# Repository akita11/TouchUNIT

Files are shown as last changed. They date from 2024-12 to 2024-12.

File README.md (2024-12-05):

# TouchUNIT

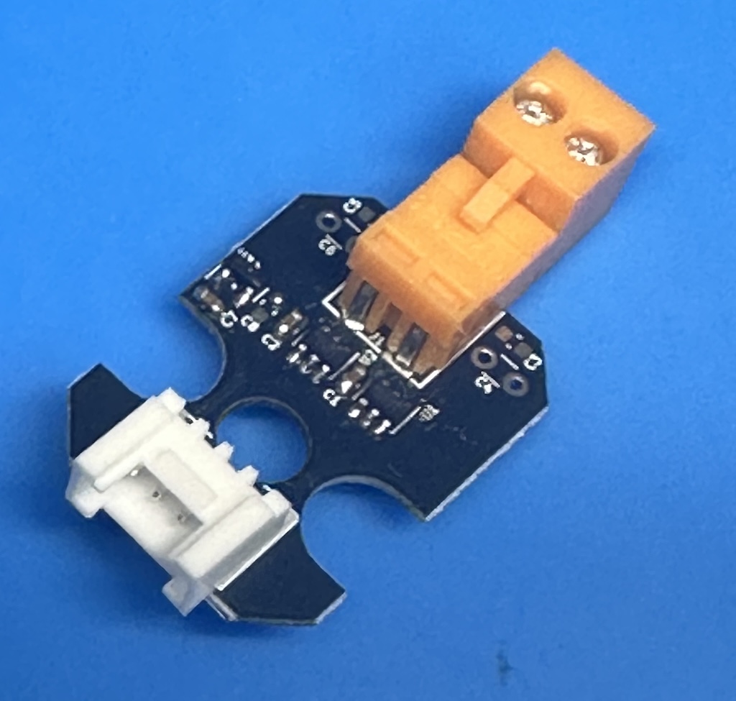
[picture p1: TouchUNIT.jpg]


タッチセンサICの[TTP223N-HA6](https://www.lcsc.com/product-detail/Touch-Sensors_Tontek-Design-Tech-TTP223N-HA6_C93723.html)を使用した、2系統のタッチセンサです。Grove端子の2本の信号線にタッチ状態を出力することができます。M5Stackの2個の物理スイッチがある[デュアルボタンUNIT](https://www.switch-science.com/products/4048)と同等の出力のため、UIFlow等ではこのデュアルボタンUNIT用のブロック・プログラムがそのまま使えます。

※[M5Stack用ADCユニット](https://www.switch-science.com/products/9491)と形状が互換なので、そのケースを流用できます。

## 使い方

オレンジのネジ端子にタッチ電極を接続します。T1とT2の独立の2系統のタッチ検出を使用できます。手を近づけただけでONとなるなどタッチ検出の感度が高すぎる場合は、後述の方法で感度を調整してください。（標準状態より感度を高めることは原理上できません）

## 設定の変更

### タッチ検出の感度の変更

基板上にコンデンサを取り付けることで、タッチ検出の感度を調整（低くする）ことができます。実際の使用状況にあわせて、適切な容量のコンデンサを接続してください。容量値や動作原理などはタッチ検出IC(TTP223N)のデータシートを参照してください。

- T1 : C3（1608サイズ表面実装）またはC4（挿入実装）
- T2 : C5（1608サイズ表面実装）またはC6（挿入実装）

### 出力信号の極性・トグルの設定

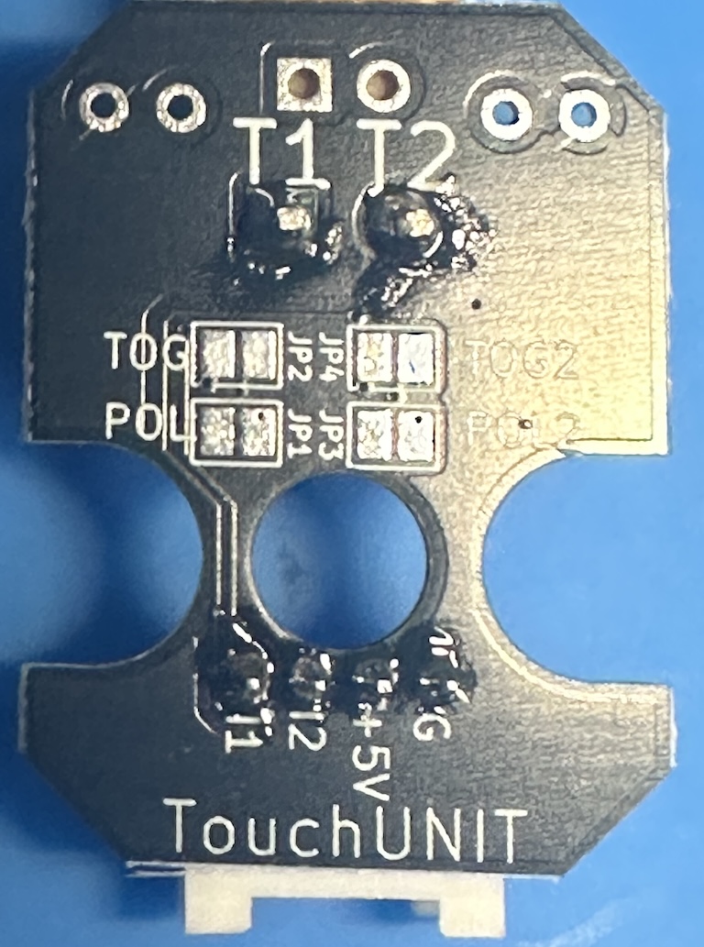
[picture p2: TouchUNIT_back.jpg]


基板裏面の半田ジャンパによって、出力の動作モードを設定できます。詳細はタッチ検出IC(TTP223N)のデータシートと回路図を参照してください。

- POL1(JP1/T1用)/POL2(JP3/T2用): ショート（標準設定）=タッチ時'0'／開放（パターンカット）=タッチ時'1'
- TOG1(JP2/T1用)/TOG2(JP4/T2用): 開放（標準設定）=タッチ時のみ0/1／ショート（半田を盛る）=タッチごとに出力がトグル

## Author

Junichi Akita (akita@ifdl.jp, @akita11)

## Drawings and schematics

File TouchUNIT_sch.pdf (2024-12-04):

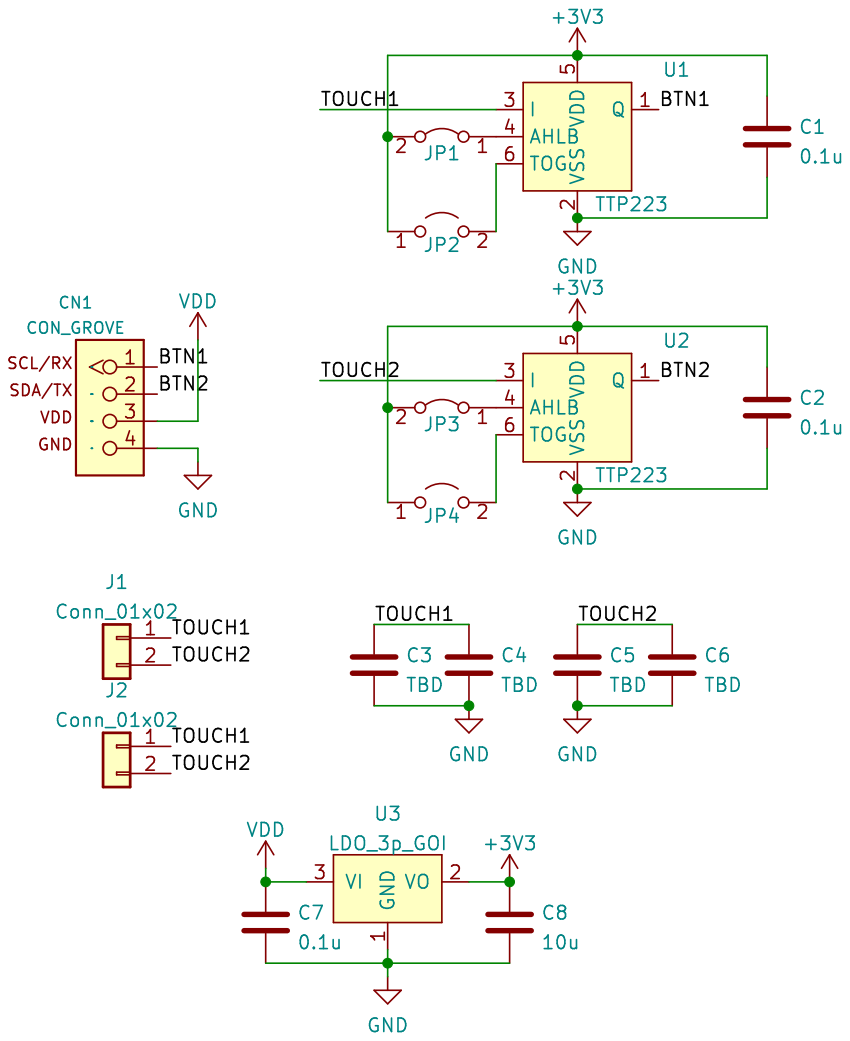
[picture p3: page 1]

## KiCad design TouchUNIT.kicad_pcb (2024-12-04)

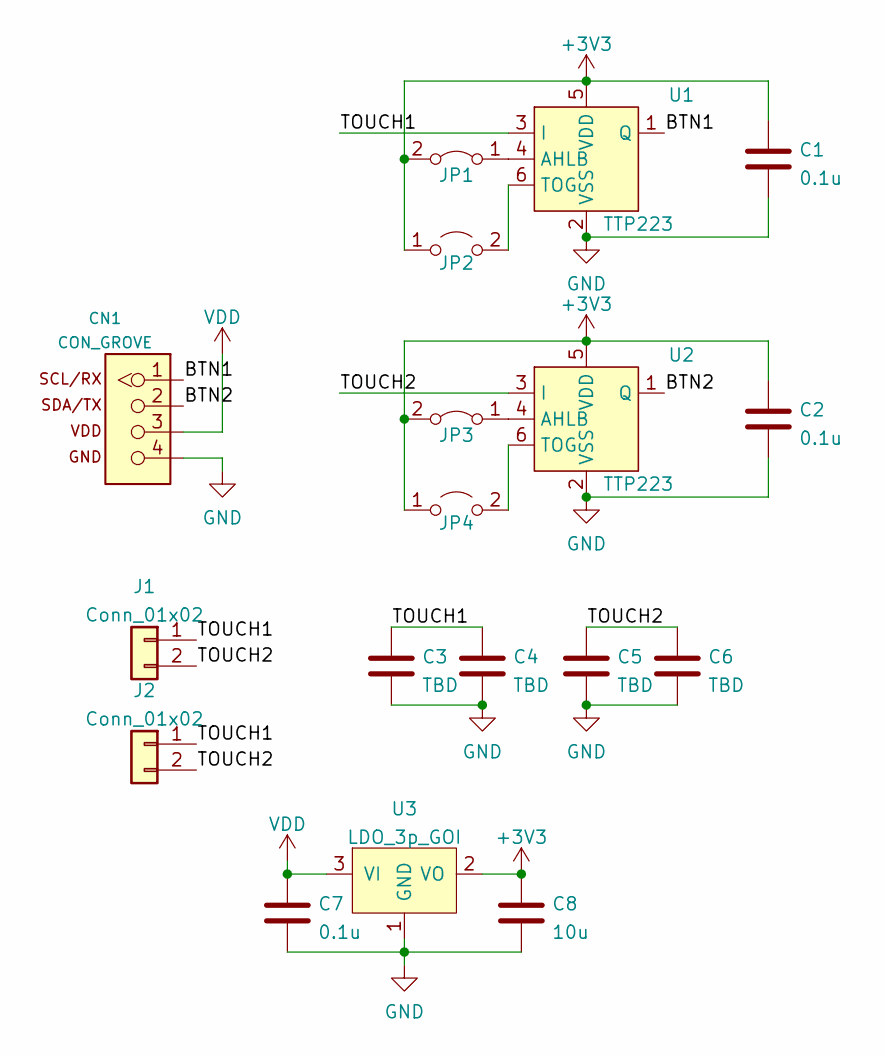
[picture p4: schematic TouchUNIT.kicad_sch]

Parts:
C1, C2, C7: 0.1u; C_0603_1608Metric
C3, C5: TBD; C_0603_1608Metric
C4, C6: TBD; C_Disc_D3.0mm_W1.6mm_P2.50mm
C8: 10u; C_0603_1608Metric
CN1: CON_GROVE; CON_GROVE_H
J1: Conn_01x02; CON_HT396R_2P
J2: Conn_01x02; PinSocket_1x02_P2.54mm_Vertical
JP1, JP3: Jumper_2_Bridged; SolderJumper-2_P1.3mm_Bridged2Bar_Pad1.0x1.5mm
JP2, JP4: Jumper_2_Open; SolderJumper-2_P1.3mm_Open_Pad1.0x1.5mm
U1, U2: TTP223; SOT-23-6
U3: LDO_3p_GOI; SOT-23

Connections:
+3V3: C1.1, C2.1, C8.1, JP1.2 (B), JP2.1 (A), JP3.2 (B), JP4.1 (A), U1.5 (VDD), U2.5 (VDD), U3.2 (VO)
/BTN1: CN1.1, U1.1 (Q)
/BTN2: CN1.2, U2.1 (Q)
/TOUCH1: C3.1, C4.1, J1.1, J2.1, U1.3 (I)
/TOUCH2: C5.1, C6.1, J1.2, J2.2, U2.3 (I)
GND: C1.2, C2.2, C3.2, C4.2, C5.2, C6.2, C7.2, C8.2, CN1.4, U1.2 (VSS), U2.2 (VSS), U3.1 (GND)
unnamed: JP1.1 (A), U1.4 (AHLB)
unnamed: JP2.2 (B), U1.6 (TOG)
unnamed: JP3.1 (A), U2.4 (AHLB)
unnamed: JP4.2 (B), U2.6 (TOG)
VDD: C7.1, CN1.3, U3.3 (VI)

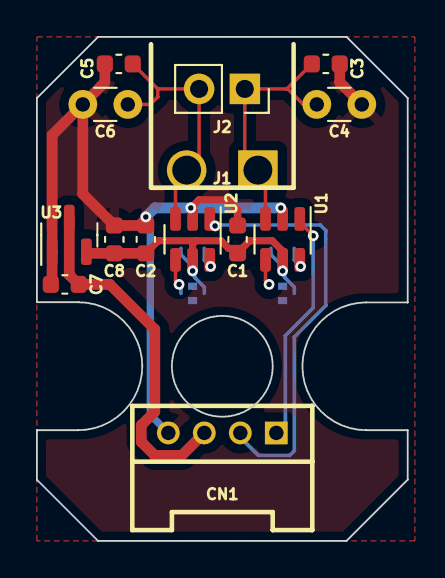
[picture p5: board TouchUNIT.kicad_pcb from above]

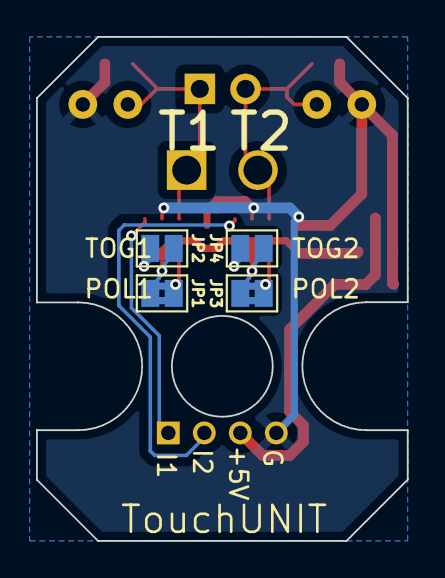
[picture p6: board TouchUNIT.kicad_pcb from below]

Board: 2 copper layers, 20.6 x 28.0 mm, 18 parts (4 on the bottom side), 11 nets.
